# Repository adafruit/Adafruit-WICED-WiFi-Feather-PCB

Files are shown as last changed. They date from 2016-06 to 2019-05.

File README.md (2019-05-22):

## Adafruit WICED WiFi Feather PCB
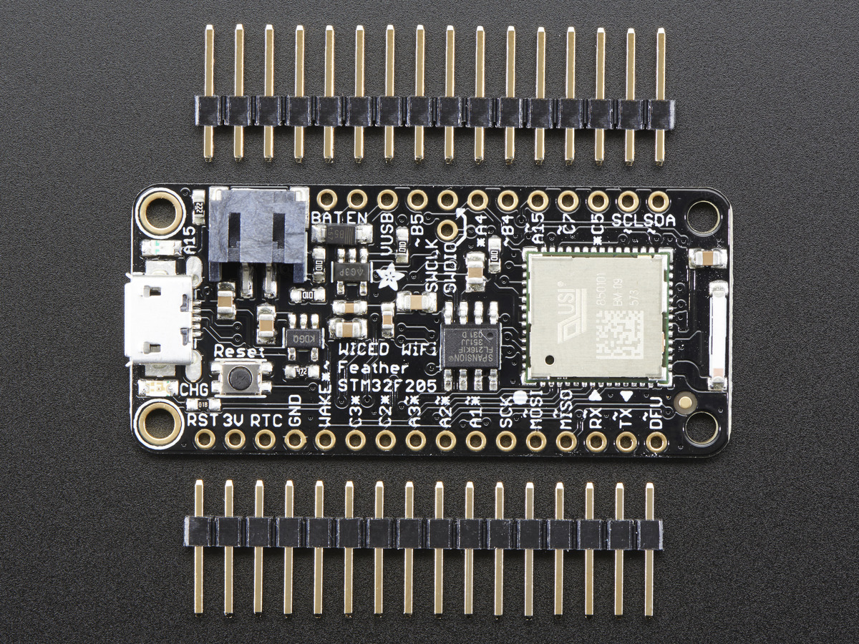
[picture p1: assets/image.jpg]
<a href="http://www.adafruit.com/products/3056"><br/>
Click here to purchase one from the Adafruit shop</a>

The WICED Feather is based on Cypress (formerly Broadcom) WICED (Wireless Internet Connectivity for Embedded Devices) platform, and is paired up with a powerful STM32F205 ARM Cortex M3 processor running at 120MHz, with support for TLS 1.2 to access sites and web services safely and securely.

PCB files for the Adafruit WICED WiFi Feather. The format is EagleCAD schematic and board layout
- https://www.adafruit.com/product/3056

### License

Adafruit invests time and resources providing this open source design, please support Adafruit and open-source hardware by purchasing products from [Adafruit](https://www.adafruit.com)!

All text above must be included in any redistribution

Designed by Limor Fried/Ladyada for Adafruit Industries.
Creative Commons Attribution/Share-Alike, all text above must be included in any redistribution. 
See license.txt for additional information.

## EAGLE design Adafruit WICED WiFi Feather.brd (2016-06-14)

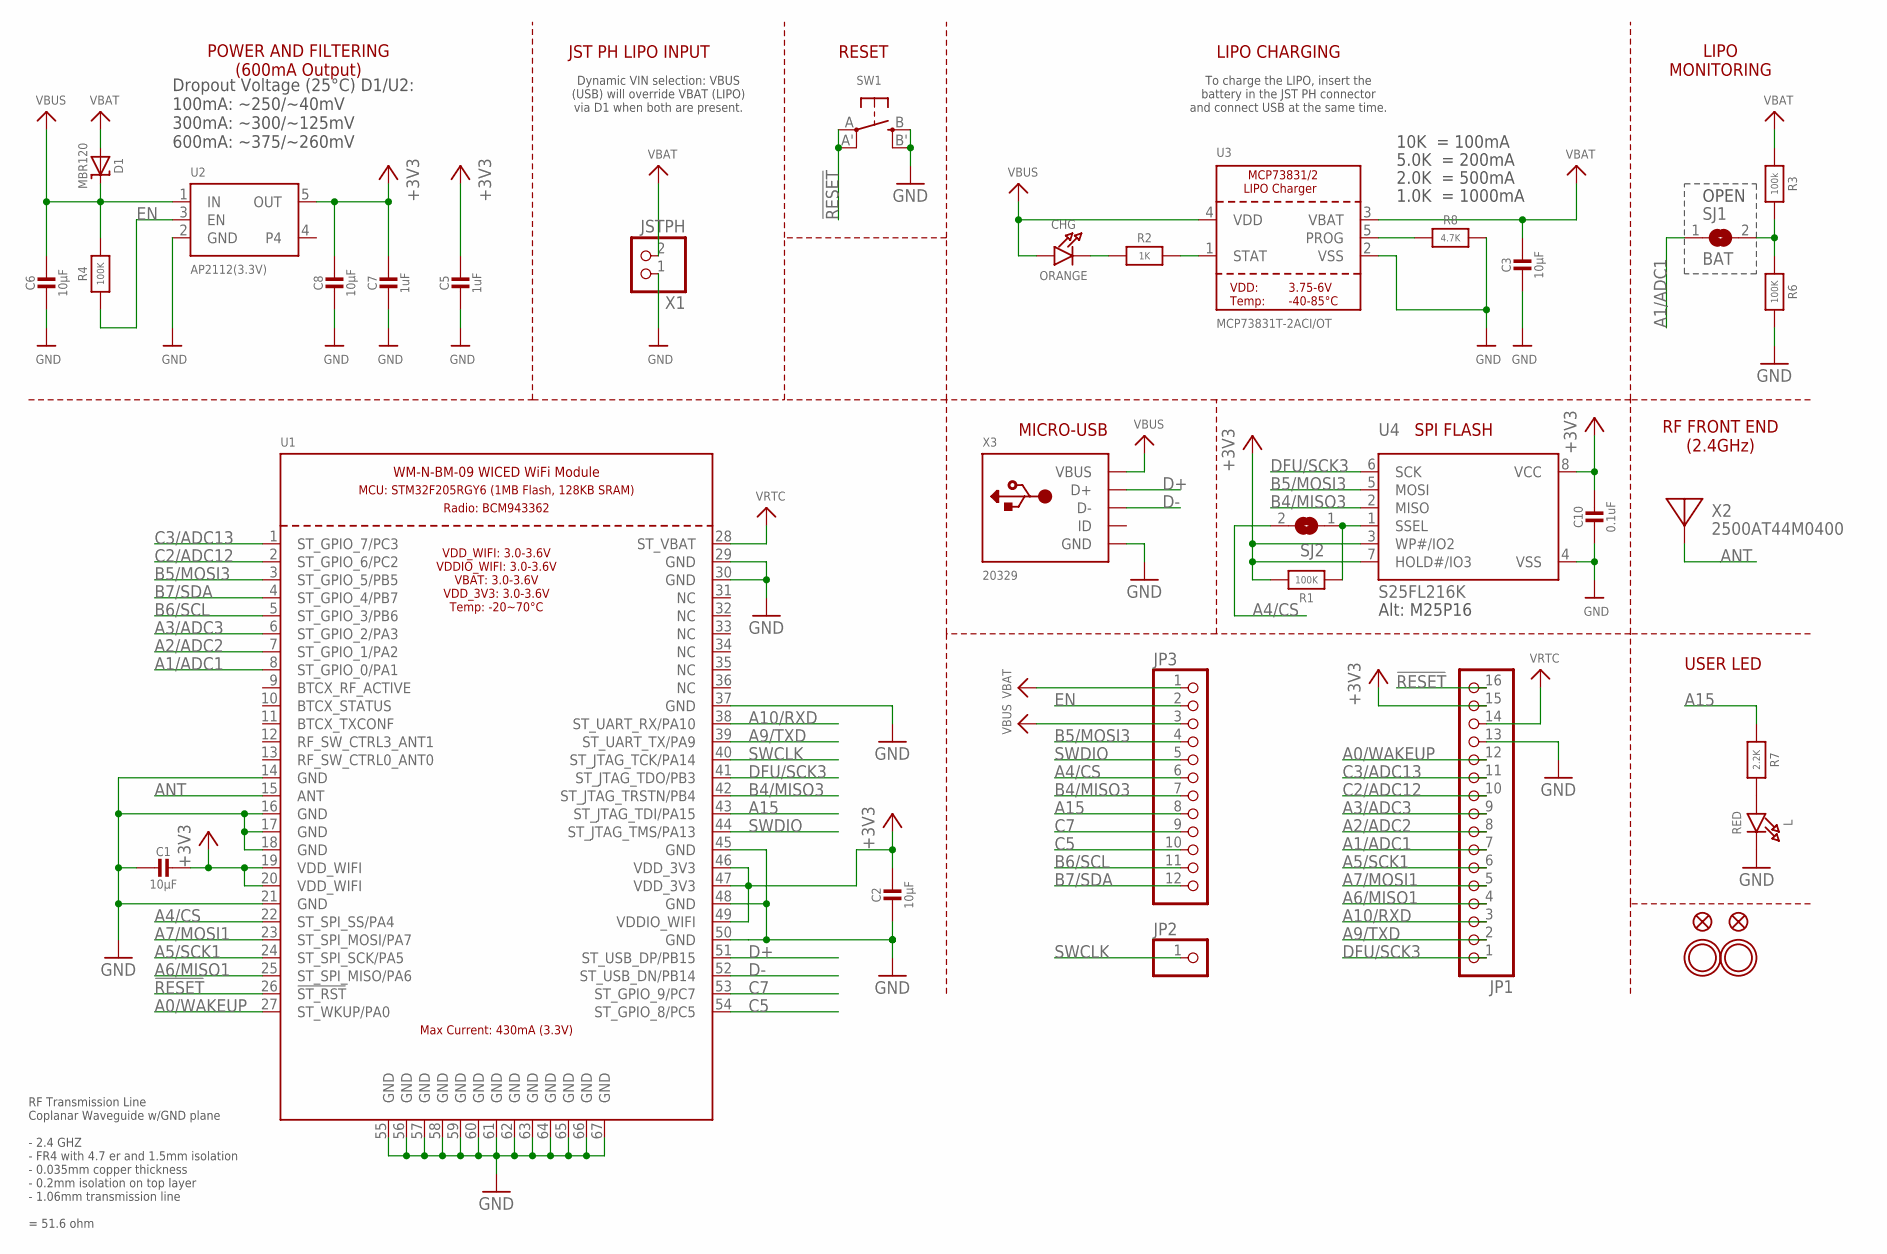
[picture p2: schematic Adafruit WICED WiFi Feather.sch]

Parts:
C1, C2, C3, C6, C8: 10µF; 0805-NO
C5, C7: 1uF; 0603-NO
C10: 0.1uF; 0805_10MGAP
CHG: ORANGE; CHIPLED_0805_NOOUTLINE
D1: MBR120; SOD-123
JP1: HEADER-1X16ROUND; 1X16_ROUND
JP2: HEADER-1X1ROUND; 1X01_ROUND
JP3: HEADER-1X12; 1X12_ROUND
L: RED; CHIPLED_0805_NOOUTLINE
R1, R4, R6: 100K; 0603-NO
R2: 1K; 0603-NO
R3: 100k; 0603-NO
R7: 2.2K; 0603-NO
R8: 4.7K; 0603-NO
SJ1: BAT; SOLDERJUMPER_REFLOW_NOPASTE
SJ2: SOLDERJUMPER; SOLDERJUMPER_ARROW_NOPASTE
SW1: SWITCH_TACT_SMT4.6X2.8; BTN_KMR2_4.6X2.8
U1: USI_WM-N-BM-09
U2: AP2112(3.3V); SOT23-5
U3: MCP73831T-2ACI/OT; SOT23-5
U4: S25FL216K; SOIC8_150MIL
U$31, U$32: MOUNTINGHOLE2.5; MOUNTINGHOLE_2.5_PLATED
U$34, U$35: FIDUCIAL""; FIDUCIAL_1MM
X1: JSTPH; JSTPH2
X2: 2500AT44M0400; ANT_2500AT44M0400
X3: 20329; 4UCONN_20329_V2

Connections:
!RESET: JP1.16, SW1.A, SW1.A' (P1), U1.26 (!ST_RST)
+3V3: C1.1, C2.1, C5.1, C7.1, C8.1, C10.1, JP1.15, R1.2, U1.19 (VDD_WIFI), U1.20 (VDD_WIFI), U1.46 (VDD_3V3), U1.47 (VDD_3V3), U1.49 (VDDIO_WIFI), U2.5 (OUT), U4.3 (WP#/IO2), U4.7 (HOLD#/IO3), U4.8 (VCC)
A0/WAKEUP: JP1.12, U1.27 (ST_WKUP/PA0)
A1/ADC1: JP1.7, SJ1.1, U1.8 (ST_GPIO_0/PA1)
A2/ADC2: JP1.8, U1.7 (ST_GPIO_1/PA2)
A3/ADC3: JP1.9, U1.6 (ST_GPIO_2/PA3)
A4/CS: JP3.6, SJ2.2, U1.22 (ST_SPI_SS/PA4)
A5/SCK1: JP1.6, U1.24 (ST_SPI_SCK/PA5)
A6/MISO1: JP1.4, U1.25 (ST_SPI_MISO/PA6)
A7/MOSI1: JP1.5, U1.23 (ST_SPI_MOSI/PA7)
A9/TXD: JP1.2, U1.39 (ST_UART_TX/PA9)
A10/RXD: JP1.3, U1.38 (ST_UART_RX/PA10)
A15: JP3.8, R7.1, U1.43 (ST_JTAG_TDI/PA15)
ANT: U1.15 (ANT), X2.FEED
B4/MISO3: JP3.7, U1.42 (ST_JTAG_TRSTN/PB4), U4.2 (MISO)
B5/MOSI3: JP3.4, U1.3 (ST_GPIO_5/PB5), U4.5 (MOSI)
B6/SCL: JP3.11, U1.5 (ST_GPIO_3/PB6)
B7/SDA: JP3.12, U1.4 (ST_GPIO_4/PB7)
C2/ADC12: JP1.10, U1.2 (ST_GPIO_6/PC2)
C3/ADC13: JP1.11, U1.1 (ST_GPIO_7/PC3)
C5: JP3.10, U1.54 (ST_GPIO_8/PC5)
C7: JP3.9, U1.53 (ST_GPIO_9/PC7)
D+: U1.51 (ST_USB_DP/PB15), X3.D+
D-: U1.52 (ST_USB_DN/PB14), X3.D-
DFU/SCK3: JP1.1, U1.41 (ST_JTAG_TDO/PB3), U4.6 (SCK)
EN: JP3.2, R4.1, U2.3 (EN)
GND: C1.2, C2.2, C3.2, C5.2, C6.2, C7.2, C8.2, C10.2, JP1.13, L.C, R6.2, R8.2, SW1.B (S), SW1.B' (S1), U1.14 (GND), U1.16 (GND), U1.17 (GND), U1.18 (GND), U1.21 (GND), U1.29 (GND), U1.30 (GND), U1.37 (GND), U1.45 (GND), U1.48 (GND), U1.50 (GND), U1.55 (GND), U1.56 (GND), U1.57 (GND), U1.58 (GND), U1.59 (GND), U1.60 (GND), U1.61 (GND), U1.62 (GND), U1.63 (GND), U1.64 (GND), U1.65 (GND), U1.66 (GND), U1.67 (GND), U2.2 (GND), U3.2 (VSS), U4.4 (VSS), X1.1, X3.BASE@1 (GND), X3.BASE@2 (GND), X3.GND, X3.SPRT@1 (GND), X3.SPRT@2 (GND), X3.SPRT@3 (GND), X3.SPRT@4 (GND)
unnamed: CHG.C, R2.1
unnamed: L.A, R7.2
unnamed: R2.2, U3.1 (STAT)
unnamed: R8.1, U3.5 (PROG)
unnamed: R3.2, R6.1, SJ1.2
unnamed: R1.1, SJ2.1, U4.1 (SSEL)
SWCLK: JP2.1, U1.40 (ST_JTAG_TCK/PA14)
SWDIO: JP3.5, U1.44 (ST_JTAG_TMS/PA13)
VBAT: C3.1, D1.A, JP3.1, R3.1, U3.3 (VBAT), X1.2
VBUS: C6.1, CHG.A, D1.C, JP3.3, R4.2, U2.1 (IN), U3.4 (VDD), X3.VBUS
VRTC: JP1.14, U1.28 (ST_VBAT)

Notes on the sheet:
POWER AND FILTERING (600mA Output)
RESET
10K = 100mA
5.0K = 200mA
2.0K = 500mA
1.0K = 1000mA
LIPO CHARGING
Alt: M25P16
MICRO-USB
SPI FLASH
USER LED
LIPO MONITORING
OPEN
RF FRONT END (2.4GHz)
JST PH LIPO INPUT
Dynamic VIN selection: VBUS (USB) will override VBAT (LIPO) via D1 when both are present.
To charge the LIPO, insert the battery in the JST PH connector and connect USB at the same time.
RF Transmission Line Coplanar Waveguide w/GND plane - 2.4 GHZ - FR4 with 4.7 er and 1.5mm isolation - 0.035mm copper thickness - 0.2mm isolation on top layer - 1.06mm transmission line = 51.6 ohm
Dropout Voltage (25°C) D1/U2: 100mA: ~250/~40mV 300mA: ~300/~125mV 600mA: ~375/~260mV

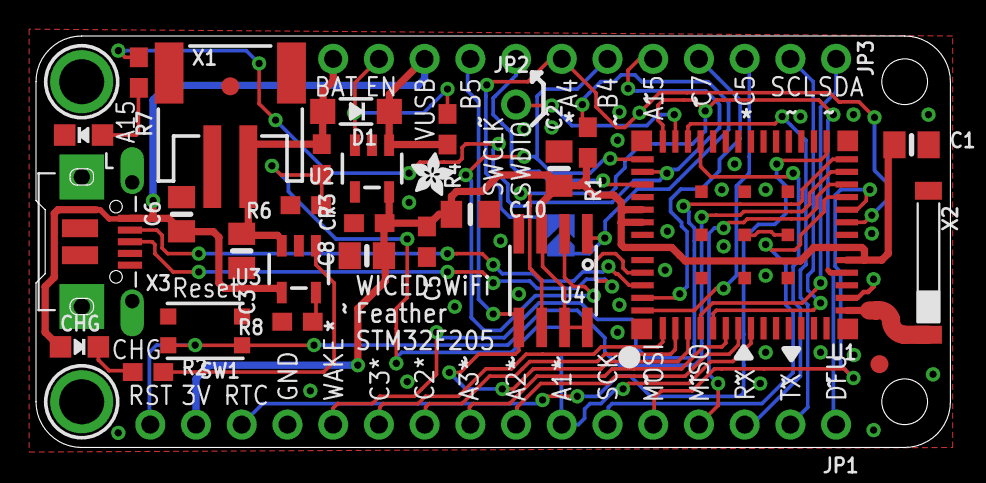
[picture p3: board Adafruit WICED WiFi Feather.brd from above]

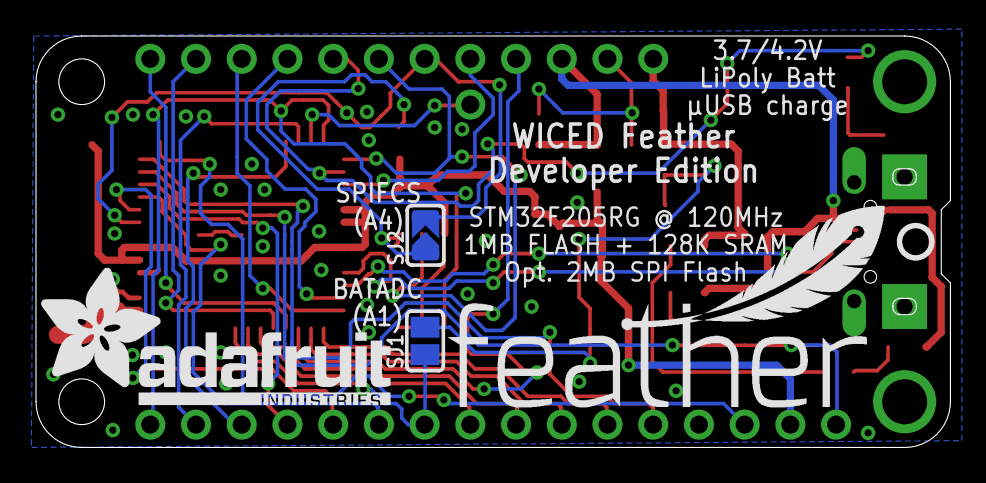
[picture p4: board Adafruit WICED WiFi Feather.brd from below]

Board: 2 copper layers, 50.8 x 22.9 mm, 39 parts (5 on the bottom side), 38 nets.

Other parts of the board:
U$7: FEATHERLOGO
U$8: ADAFRUIT_2.5MM
U$10: ADAFRUIT_TEXT_20MM
U$23: PCBFEAT-REV-040

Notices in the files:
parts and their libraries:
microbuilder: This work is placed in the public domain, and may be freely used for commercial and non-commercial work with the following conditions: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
